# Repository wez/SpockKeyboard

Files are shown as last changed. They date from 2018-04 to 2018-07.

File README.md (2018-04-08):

# "Spock" Keyboard

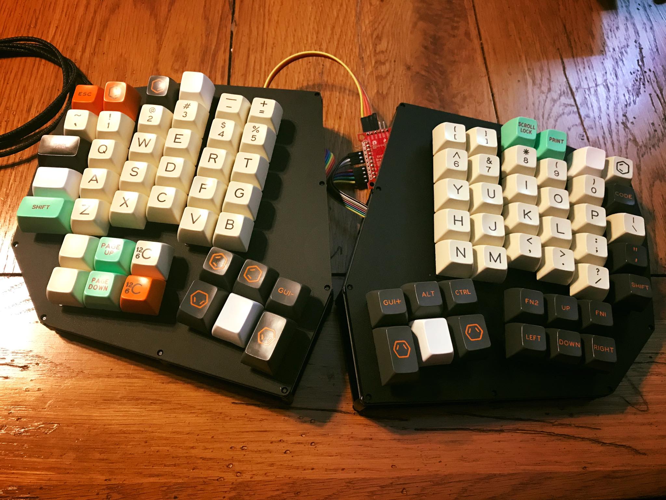
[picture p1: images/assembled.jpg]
Assembled board


This repo holds schematics and code for the Spock keyboard that was
designed by me (Wez Furlong) and modeled on my hands.

The keyboard is a split ergonomic layout in an ortholinear (straight columns,
aligned to your fingers rather than staggered) arrangement with splayed columns
that more closely match the finger separation when the hand is at rest,
thumb clusters to make use of the strong but underused thumbs and a cluster
for classic inverted-T arrow keys.

The Spock name comes from the finger splay which is reminiscent of the Vulcan
hand gesture.

The initial hardware revision is designed around a prototyping friendly
arrangement, with the PCB set up with a minimized keyboard matrix (saving the
headache of routing the matrix while soldering) that is terminated at header
blocks.  No controller hardware is proscribed, making this a more convenient
physical base for experimenting with different controller and interfaces (USB,
BLE and so on).

## What's in this repo?

The hardware directory holds the kicad pcb defintion, gerber files and plate
definitions suitable for building a sandwich style case.  The PCB and gerber
files meet the DRC requirements for [Seeed's PCB fabrication service](https://www.seeedstudio.com/fusion_pcb.html).
The case design files are suitable for use with [Ponoko's service](http://www.ponoko.com).

The Spockduino directory holds some basic code for a keyboard firmware that uses
the Adafruit Feather M0 Express controller, and a SparkFun SX1509 breakout to
implement a USB keyboard.

## Keyboard Layout Editor

You can view the layout for the left hand here:

http://www.keyboard-layout-editor.com/#/gists/912c57ebc2bcc78ba9ccc6bbb83db161

## Bill of Materials

Should you decide to build one of these for yourself, you will need:

* 84 x Cherry MX compatible PCB mount key switches (each half requires 42)
* 70 x 1u Cherry MX key caps
* 8 x 1.25u Cherry MX key caps
* 6 x 1.5u Cherry MX key caps
* 84 x 1N4148 signal diodes
* 20 x M3 spacer to hold the case top and bottom apart.  Choose the height
  that meets your taste and internal electroncs selection.
* 20 x M3 nuts
* 20 x M3 screws
* Top and bottom plate.  See [hardware/spock-case-ponoko-p2.svg](https://github.com/wez/SpockKeyboard/blob/master/hardware/spock-case-ponoko-p2.svg) for left+right and top+bottom.
  I recommend using matte acrylic for its appealing combination of weight, appearance and price.
  Note that you don't strictly need the plates if you want to rock a bare PCB, but you should
  take care to avoid shorting the contacts under the PCB.
* 2x 2x12 header block.  Pick this to match your wiring.  I used right angled
  male header block to save on vertical space.
* Microcontroller of your choice.  I'm using an [Adafruit Feather M0 Express](https://www.adafruit.com/product/3403)
  with the Spockduino code.  You should be able to use other Feather boards without
  changing the wiring.
* 1x [SX1509 IO Expander](https://www.sparkfun.com/products/13601)
* Misc jumper wires
* 2x Jack and 1x connecting cable with 4+ wires.  Some folks like [TRRS](https://www.sparkfun.com/products/11570) audio cables and
  jacks, and others like [RJ45 jacks](https://www.sparkfun.com/products/643) ([+breakout](https://www.sparkfun.com/products/716)) and cables.

note: you can trade two of the 1.25u key caps in the thumb clusters for 1u to make
room to trade two of the other 1.25u caps with 1.5u caps for a total of 72x 1u caps,
4x 1.25u caps and 8x 1.5u caps.

There are no explicitly designed in attachment points for the controller, expander
or jacks so you may want to apply friction, tape or hot glue as suits your taste
and overall assembly.

## Wiring/Assembly

The PCB is reversible and can be used for a left or right hand.  For left hand
assembly you will place the switches and diodes on the side that has the
keyswitch labels (eg: `k01` through `k77`).  For the right hand you will place
them on the other side of the board.

If you are using the top plate, take care to assemble in the order described
below as it can be difficult to go back to correct a missed step once you
start soldering the keyswitches.

This initial rev is designed for prototyping, so I attached header to the Feather
and expander breakout boards and used jumper cables to connect them up.  Play
around with this before you start soldering keyswitches to make sure that you
can fit everything together.

1. Solder the diodes first.  The black bar of the diode must be aligned to the thicker
   white bar.  For the left hand the diodes go in on the side with the `dkXX` labels,
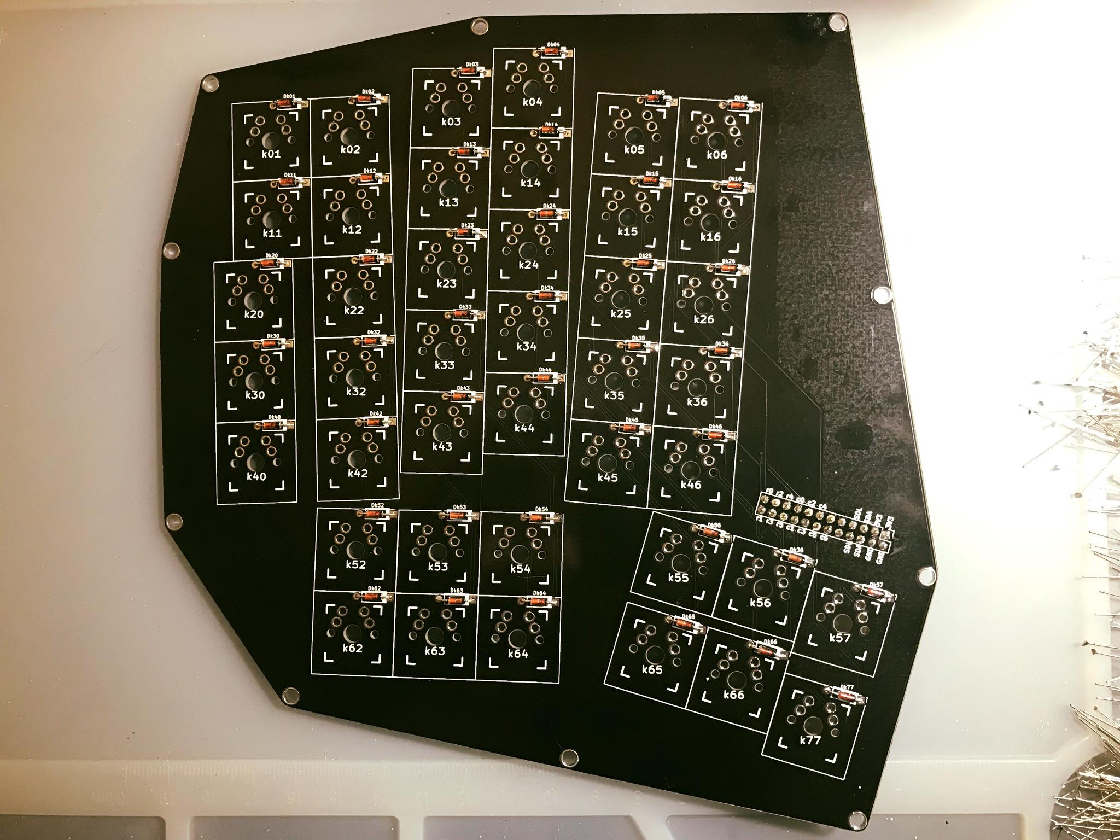
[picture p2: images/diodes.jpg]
diodes
   for the right hand they go on the opposite side. 
2. Solder the header block second.  If you are using a plate the header pins must be
   on the other side of the board from the diodes.  If you are rocking a plateless
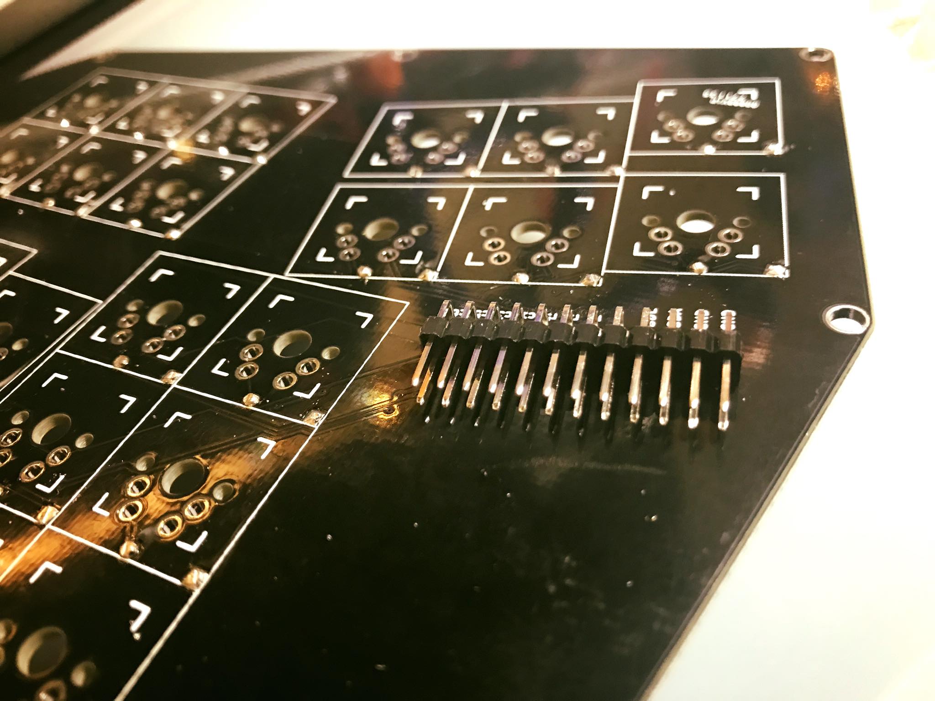
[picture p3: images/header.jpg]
header
   build then you may want the header pins on the top side. 
3. If using a plate, insert the M3 nuts and spacers now.  The nuts go on the same side
   as the diodes, with the spacers on the other side.
4. Place the plate; it goes on the same side as the diodes and should click in
   and lightly grip on the top of the M3 spacers where they protude through
   the M3 nuts
5. Place the key switches through the plate.  The switch stem should be on the same
   side of the board as the diodes and plate.  The switch should friction fit
   in the PCB.  Take care to check that both of the pins on the underside of
   the switch are protuding from the holds on the reverse of the PCB.  You should
   see the pins in the holes and they may protude by about 1mm.  It is possible to
   fold a pin over when placing it, so you may need to wiggle it out of the plate and pcb and
   straighten up the pin.   Make sure that you check every switch!
6. Satisfy yourself that you can assemble the case and house the controller and expander
   before you go further.
7. Solder in the key switches.  Make sure that you solder both pins on each switch!

The Spockduino code assumes that you connected the pins like this:

### Feather

The Feather is attached to the left hand.  Take care: the header block
labels on the backside are wrong; see the errata below!

* Pins labelled `A0`-`A5` on the left side are connected to `r0`-`r5` in the header block
* Pins labelled `5`-`12` on the right side are connected to `c0`-`c6` in the header block
* `3V3`, `GND`, `SDA`, `SDL` are connected to the pins with the same names
  on the IO expander.  These 4 lines are intended to be carried over
  the connecting cable between the halves so you may want to connect the
  feather to a TRRS or RJ45 block and do the same on the other half
  for the Expander

### SX 1509

The SX1509 is attached to the right hand. Take care: the header block
labels on the backside are wrong; see the errata below!

* Pins `0`-`5` are connected to `r0`-`r5` in the header block.
* Pins `8`-`14` are connected to `c0`-`c6` in the header block.
* `3V3`, `GND`, `SDA`, `SDL` are connected to the pins with the same names
  on the Feather as noted above.

### Flashing

Use the arduino IDE to upload the spock sketch to the device.  I found
that this often requires a couple of attempts with the Feather M0 Express,
as the bootloader seems to take a little longer to kick in than the uploader
expects.

## Errata

The first and current rev of the PCB design has incorrect labels for the header
block on the back side of the PCB.  The labels on the front side are correct.
In case you are unsure which is the front, the front side of the pcb also has
labels for the switch positions.

## License and Copying

Unless stated in individual files, the contents of this repo are made available
under the terms of the MIT License.

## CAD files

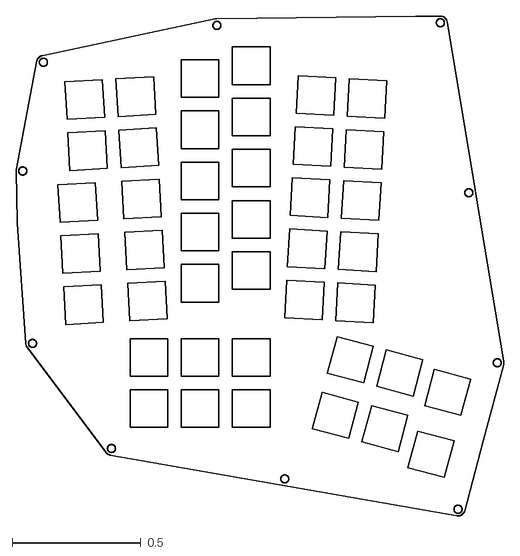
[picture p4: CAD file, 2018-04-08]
hardware/switch-plate-full.dxf
1.89 x 1.94

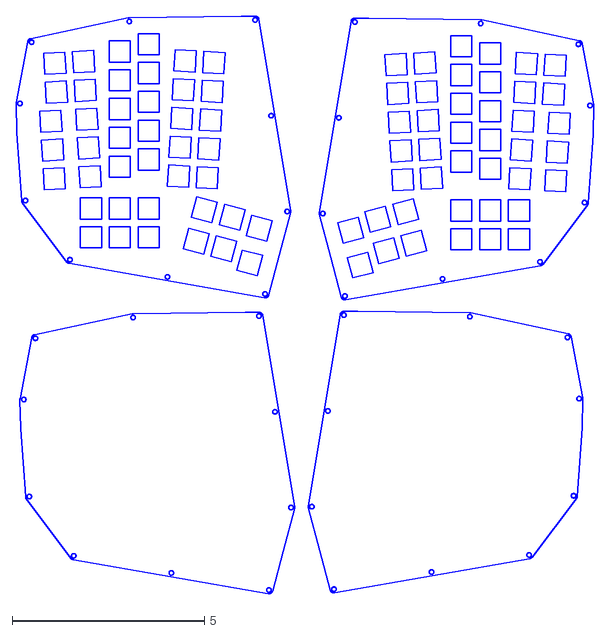
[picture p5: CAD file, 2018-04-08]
hardware/spock-case-ponoko-p2.dxf
15.0 x 15.0

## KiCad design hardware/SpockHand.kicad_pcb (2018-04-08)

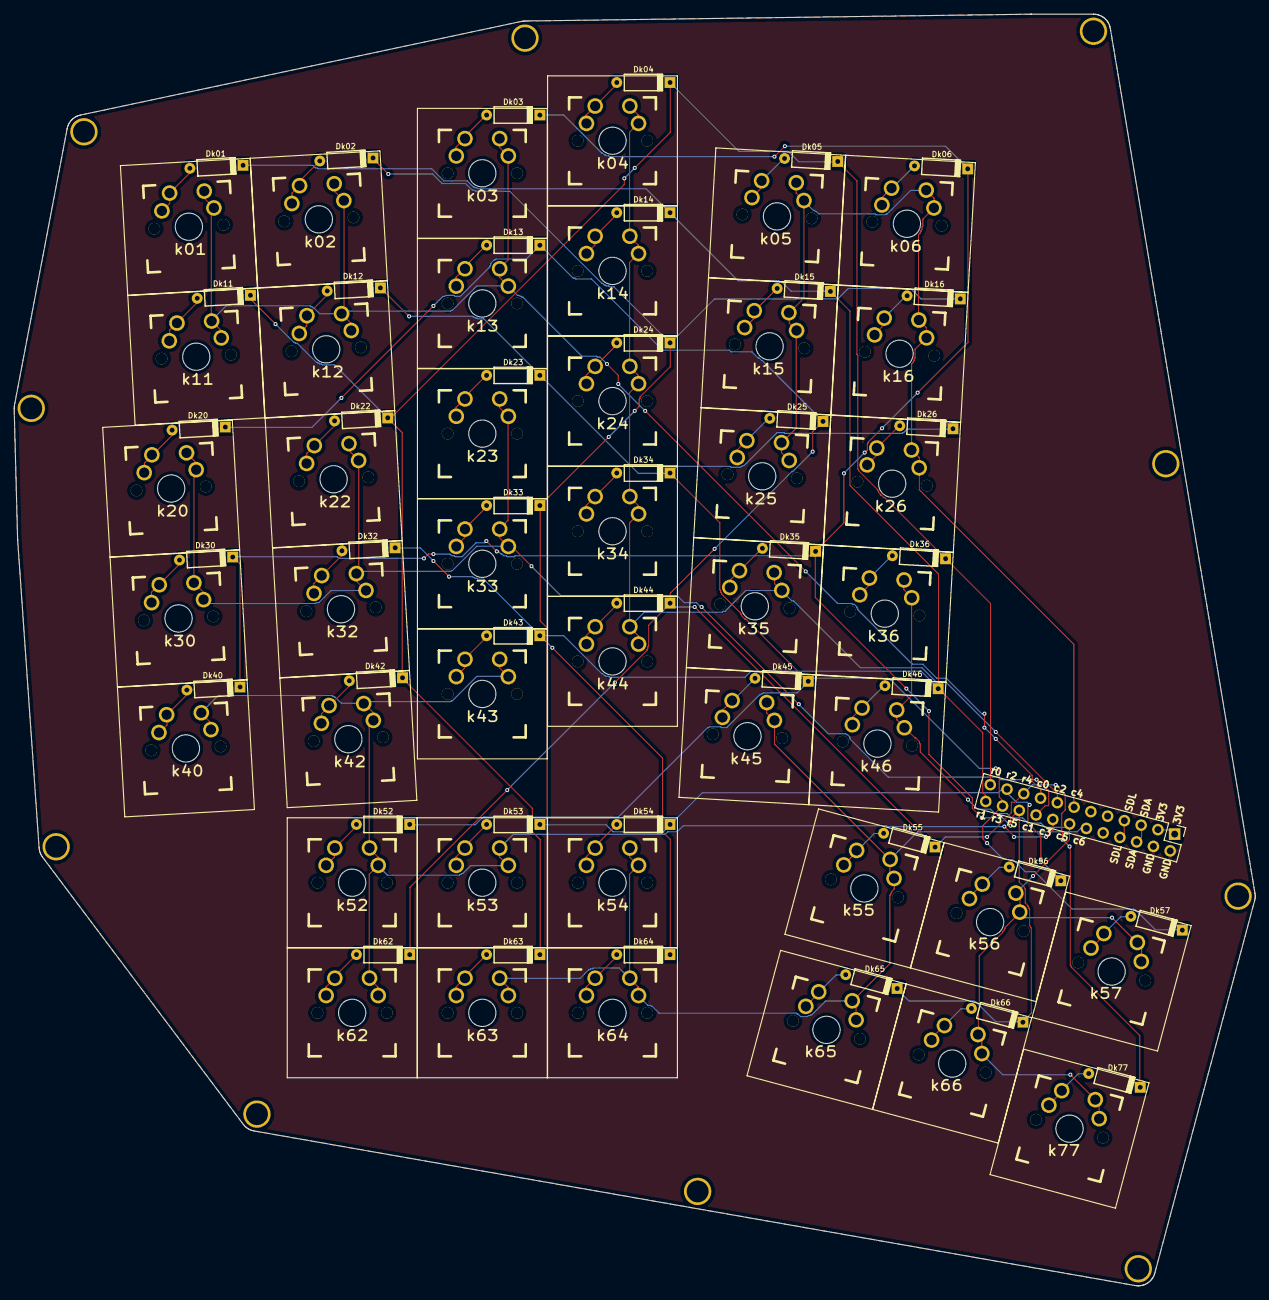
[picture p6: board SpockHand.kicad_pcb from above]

Board: 2 copper layers, 181.6 x 186.1 mm, 94 parts (0 on the bottom side), 55 nets.

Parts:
CP0: VAL**; CP0
CP1: VAL**; CP1
CP2: VAL**; CP2
CP3: VAL**; CP3
CP4: VAL**; CP4
CP5: VAL**; CP5
CP6: VAL**; CP6
CP7: VAL**; CP7
CP8: VAL**; CP8
CP9: VAL**; CP9
Dk01: D; Dk01
Dk02: D; Dk02
Dk03: D; Dk03
Dk04: D; Dk04
Dk05: D; Dk05
Dk06: D; Dk06
Dk11: D; Dk11
Dk12: D; Dk12
Dk13: D; Dk13
Dk14: D; Dk14
Dk15: D; Dk15
Dk16: D; Dk16
Dk20: D; Dk20
Dk22: D; Dk22
Dk23: D; Dk23
Dk24: D; Dk24
Dk25: D; Dk25
Dk26: D; Dk26
Dk30: D; Dk30
Dk32: D; Dk32
Dk33: D; Dk33
Dk34: D; Dk34
Dk35: D; Dk35
Dk36: D; Dk36
Dk40: D; Dk40
Dk42: D; Dk42
Dk43: D; Dk43
Dk44: D; Dk44
Dk45: D; Dk45
Dk46: D; Dk46
Dk52: D; Dk52
Dk53: D; Dk53
Dk54: D; Dk54
Dk55: D; Dk55
Dk56: D; Dk56
Dk57: D; Dk57
Dk62: D; Dk62
Dk63: D; Dk63
Dk64: D; Dk64
Dk65: D; Dk65
Dk66: D; Dk66
Dk77: D; Dk77
k01: >VALUE; k01
k02: >VALUE; k02
k03: >VALUE; k03
k04: >VALUE; k04
k05: >VALUE; k05
k06: >VALUE; k06
k11: >VALUE; k11
k12: >VALUE; k12
k13: >VALUE; k13
k14: >VALUE; k14
k15: >VALUE; k15
k16: >VALUE; k16
k20: >VALUE; k20
k22: >VALUE; k22
k23: >VALUE; k23
k24: >VALUE; k24
k25: >VALUE; k25
k26: >VALUE; k26
k30: >VALUE; k30
k32: >VALUE; k32
k33: >VALUE; k33
k34: >VALUE; k34
k35: >VALUE; k35
k36: >VALUE; k36
k40: >VALUE; k40
k42: >VALUE; k42
k43: >VALUE; k43
k44: >VALUE; k44
k45: >VALUE; k45
k46: >VALUE; k46
k52: >VALUE; k52
k53: >VALUE; k53
k54: >VALUE; k54
k55: >VALUE; k55
k56: >VALUE; k56
k57: >VALUE; k57
k62: >VALUE; k62
k63: >VALUE; k63
k64: >VALUE; k64
k65: >VALUE; k65
k66: >VALUE; k66
k77: >VALUE; k77

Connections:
unnamed: Dk11.2, k11.2, k11.2a
unnamed: Dk22.2, k22.2, k22.2a
unnamed: Dk04.2, k04.2, k04.2a
unnamed: Dk42.2, k42.2, k42.2a
unnamed: Dk05.2, k05.2, k05.2a
unnamed: Dk36.2, k36.2, k36.2a
unnamed: Dk63.2, k63.2, k63.2a
unnamed: Dk01.2, k01.2, k01.2a
unnamed: Dk32.2, k32.2, k32.2a
unnamed: Dk14.2, k14.2, k14.2a
unnamed: Dk43.2, k43.2, k43.2a
unnamed: Dk15.2, k15.2, k15.2a
unnamed: Dk46.2, k46.2, k46.2a
unnamed: Dk64.2, k64.2, k64.2a
unnamed: Dk02.2, k02.2, k02.2a
unnamed: Dk33.2, k33.2, k33.2a
unnamed: Dk24.2, k24.2, k24.2a
unnamed: Dk53.2, k53.2, k53.2a
unnamed: Dk16.2, k16.2, k16.2a
unnamed: Dk56.2, k56.2, k56.2a
unnamed: Dk54.2, k54.2, k54.2a
unnamed: Dk12.2, k12.2, k12.2a
unnamed: Dk23.2, k23.2, k23.2a
unnamed: Dk34.2, k34.2, k34.2a
unnamed: Dk52.2, k52.2, k52.2a
unnamed: Dk26.2, k26.2, k26.2a
unnamed: Dk57.2, k57.2, k57.2a
unnamed: Dk45.2, k45.2, k45.2a
unnamed: Dk13.2, k13.2, k13.2a
unnamed: Dk20.2, k20.2, k20.2a
unnamed: Dk44.2, k44.2, k44.2a
unnamed: Dk62.2, k62.2, k62.2a
unnamed: Dk25.2, k25.2, k25.2a
unnamed: Dk77.2, k77.2, k77.2a
unnamed: Dk55.2, k55.2, k55.2a
unnamed: Dk03.2, k03.2, k03.2a
unnamed: Dk30.2, k30.2, k30.2a
unnamed: Dk35.2, k35.2, k35.2a
unnamed: Dk40.2, k40.2, k40.2a
unnamed: Dk06.2, k06.2, k06.2a
unnamed: Dk66.2, k66.2, k66.2a
unnamed: Dk65.2, k65.2, k65.2a
col0: k01.1, k01.1a, k02.1, k02.1a, k03.1, k03.1a, k11.1, k11.1a, k12.1, k12.1a, k13.1, k13.1a
col1: k20.1, k20.1a, k22.1, k22.1a, k23.1, k23.1a, k30.1, k30.1a, k32.1, k32.1a, k33.1, k33.1a
col2: k04.1, k04.1a, k14.1, k14.1a, k24.1, k24.1a, k34.1, k34.1a, k35.1, k35.1a, k44.1, k44.1a
col3: k40.1, k40.1a, k42.1, k42.1a, k43.1, k43.1a, k52.1, k52.1a, k53.1, k53.1a, k62.1, k62.1a
col4: k05.1, k05.1a, k06.1, k06.1a, k15.1, k15.1a, k16.1, k16.1a, k25.1, k25.1a, k26.1, k26.1a
col5: k36.1, k36.1a, k46.1, k46.1a, k56.1, k56.1a, k57.1, k57.1a, k66.1, k66.1a, k77.1, k77.1a
col6: k45.1, k45.1a, k54.1, k54.1a, k55.1, k55.1a, k63.1, k63.1a, k64.1, k64.1a, k65.1, k65.1a
row0: Dk04.1, Dk05.1, Dk11.1, Dk22.1, Dk36.1, Dk42.1, Dk63.1
row1: Dk01.1, Dk14.1, Dk15.1, Dk32.1, Dk43.1, Dk46.1, Dk64.1
row2: Dk02.1, Dk16.1, Dk24.1, Dk33.1, Dk53.1, Dk54.1, Dk56.1
row3: Dk12.1, Dk23.1, Dk26.1, Dk34.1, Dk45.1, Dk52.1, Dk57.1
row4: Dk13.1, Dk20.1, Dk25.1, Dk44.1, Dk55.1, Dk62.1, Dk77.1
row5: Dk03.1, Dk06.1, Dk30.1, Dk35.1, Dk40.1, Dk65.1, Dk66.1

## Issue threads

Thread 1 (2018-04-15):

Will it support QMK eventually ?

harshitgoel96, 2018-04-15:
Hi @wez

I love the design of the keyboard. It looks like it is currently running a very basic firmware. I just want to know if it would ever run QMK ?

wez, 2018-04-15:
It shouldn't be especially difficult to get QMK running for this board.  I didn't start with QMK because QMK is still reasonably AVR centric and the controller I'm using didn't have great support last time I checked.  The hardest part is the matrix/keymap stuff, but that is already basically there as the KEYMAP macro I've used here is deliberately similar to the QMK style.

However, I don't have immediate plans to port QMK to this board myself.

harshitgoel96, 2018-04-19:
Feather 32u4 is supported by QMK out of the box. So I am assuming you are using M0 variant of feather. well its a nice layout, I might build one eventually as the ergodox I have is not for my hand. I have long fingers but short thumb. so this results in very bad thumb cluster reach.

wez, 2018-09-12:
I just pushed support for QMK to my own qmk fork; see the commit referenced above!

Closed 2018-09-12.

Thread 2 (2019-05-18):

nRF52 Split Bluetooth Keyboard

shaoyuan1943, 2019-05-18:
Hi, wez
I don't know your email so I'm sorry to bother you on github. I saw your Split Bluetooth Keyboard build log in here: https://gist.github.com/wez/b30683a4dfa329b86b9e0a2811a8c593

I have two nRF52832 board, so I want to build split bluetooth keyboard like you, but now I get a problem. One nRF52832 is central(right hand), one is peripheral(left hand), right hand connect left hand by UART and read left hand key matrix, at last, right hand send key matrix by bluetooth-hid to PC.

**The problem is: when two nRF52832 board connected and right hand read key matrix succeed, but right hand HID send key matrix failed, I don't know why, I can't found any documents for that.**

// reported is false
bool reported = hid.keyboardReport(mods, report);

Can you help let me know why? Thank you very much for your gist.

Best regards.
lennon.c

Closed 2019-05-20.

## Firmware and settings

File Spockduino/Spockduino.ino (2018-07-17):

#define WAT 0
#include "HID.h"
#include "HIDTables.h"
#include "Keyboard.h"

#define HID_KEYBOARD_A HID_KEYBOARD_A_AND_A
#define HID_KEYBOARD_B HID_KEYBOARD_B_AND_B
#define HID_KEYBOARD_C HID_KEYBOARD_C_AND_C
#define HID_KEYBOARD_D HID_KEYBOARD_D_AND_D
#define HID_KEYBOARD_E HID_KEYBOARD_E_AND_E
#define HID_KEYBOARD_F HID_KEYBOARD_F_AND_F
#define HID_KEYBOARD_G HID_KEYBOARD_G_AND_G
#define HID_KEYBOARD_H HID_KEYBOARD_H_AND_H
#define HID_KEYBOARD_I HID_KEYBOARD_I_AND_I
#define HID_KEYBOARD_J HID_KEYBOARD_J_AND_J
#define HID_KEYBOARD_K HID_KEYBOARD_K_AND_K
#define HID_KEYBOARD_L HID_KEYBOARD_L_AND_L
#define HID_KEYBOARD_M HID_KEYBOARD_M_AND_M
#define HID_KEYBOARD_N HID_KEYBOARD_N_AND_N
#define HID_KEYBOARD_O HID_KEYBOARD_O_AND_O
#define HID_KEYBOARD_P HID_KEYBOARD_P_AND_P
#define HID_KEYBOARD_Q HID_KEYBOARD_Q_AND_Q
#define HID_KEYBOARD_R HID_KEYBOARD_R_AND_R
#define HID_KEYBOARD_S HID_KEYBOARD_S_AND_S
#define HID_KEYBOARD_T HID_KEYBOARD_T_AND_T
#define HID_KEYBOARD_U HID_KEYBOARD_U_AND_U
#define HID_KEYBOARD_V HID_KEYBOARD_V_AND_V
#define HID_KEYBOARD_W HID_KEYBOARD_W_AND_W
#define HID_KEYBOARD_X HID_KEYBOARD_X_AND_X
#define HID_KEYBOARD_Y HID_KEYBOARD_Y_AND_Y
#define HID_KEYBOARD_Z HID_KEYBOARD_Z_AND_Z

#define HID_KEYBOARD_BRACKET_RIGHT HID_KEYBOARD_RIGHT_BRACKET_AND_RIGHT_CURLY_BRACE
#define HID_KEYBOARD_BRACKET_LEFT HID_KEYBOARD_LEFT_BRACKET_AND_LEFT_CURLY_BRACE
#define HID_KEYBOARD_APOSTROPHE HID_KEYBOARD_QUOTE_AND_DOUBLEQUOTE
#define HID_KEYBOARD_GRAVE HID_KEYBOARD_GRAVE_ACCENT_AND_TILDE

#define HID_KEYBOARD_1 HID_KEYBOARD_1_AND_EXCLAMATION_POINT
#define HID_KEYBOARD_2 HID_KEYBOARD_2_AND_AT
#define HID_KEYBOARD_3 HID_KEYBOARD_3_AND_POUND
#define HID_KEYBOARD_4 HID_KEYBOARD_4_AND_DOLLAR
#define HID_KEYBOARD_5 HID_KEYBOARD_5_AND_PERCENT
#define HID_KEYBOARD_6 HID_KEYBOARD_6_AND_CARAT
#define HID_KEYBOARD_7 HID_KEYBOARD_7_AND_AMPERSAND	
#define HID_KEYBOARD_8 HID_KEYBOARD_8_AND_ASTERISK	
#define HID_KEYBOARD_9 HID_KEYBOARD_9_AND_LEFT_PAREN	
#define HID_KEYBOARD_0 HID_KEYBOARD_0_AND_RIGHT_PAREN

#define KEYBOARD_MODIFIER_LEFTCTRL 1<<0
#define KEYBOARD_MODIFIER_LEFTSHIFT 1<<1
#define KEYBOARD_MODIFIER_LEFTALT 1<<2
#define KEYBOARD_MODIFIER_LEFTGUI 1<<3
#define KEYBOARD_MODIFIER_RIGHTCTRL 1<<4
#define KEYBOARD_MODIFIER_RIGHTSHIFT 1<<5
#define KEYBOARD_MODIFIER_RIGHTALT 1<<6
#define KEYBOARD_MODIFIER_RIGHTGUI 1<<7


#include "keymap.h"
#include "keyscanner.h"


void setup() 
{
#if WAT
  Serial.begin(115200);
#endif
  Keyboard.begin();

  initKeyScanner();
  resetKeyMatrix();
}

void loop() 
{
  applyMatrix();
}

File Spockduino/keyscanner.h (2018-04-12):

#pragma once
#include "sx1509.h"

// This file holds the code that scans the keyboard matrix.
// It uses an SX1509 IO expander to read the matrix for the
// right hand side and an Adafruit Feather M0 for the left
// hand side.  The readMatrix() function is the main function
// of interest.

// NOTE: if you change the row or column mappings here, you
// will probably also need to change the KEYMAP macro defined
// in keymap.h.
// These are the pin assignments to the Feather M0 Express.
// The array lists the c0-c6 column assignments to the
// header block.
static const int colPins[] = {5,6,9,10,11,12,13};
// These are r0-r5 assignments
static const int rowPins[] = {14,15,16,17,18,19};

// These are pin assignments to the sx1509 IO multiplexer.
// The column pins are attached to c0-c6, and the row
// pins to r0-r5
static const int expColPins[] = {8,9,10,11,12,13,14};
static const int expRowPins[] = {0,1,2,3,4,5};

static struct matrix_t debounceMatrix;
static struct matrix_t localMatrix;
static constexpr int kDebounceIterations = 1;
static int debouncing = kDebounceIterations;
static SX1509 expander;

void initKeyScanner() {
  expander.init();
  memset(&debounceMatrix, 0, sizeof(debounceMatrix));
  memset(&localMatrix, 0, sizeof(localMatrix));
  debouncing = kDebounceIterations;

  // Set all the rows to output-high
  for (const auto &pin : rowPins) {
    pinMode(pin, OUTPUT);
    digitalWrite(pin, HIGH);
  }

  // 0 is output
  expander.directionA(0b11000000);
  // 1 is high
  expander.dataA(0b00111111);

  // Set all the columns to input-pullup
  for (const auto &pin : colPins) {
    pinMode(pin, INPUT_PULLUP);
  }

  // 1 is input
  expander.directionB(0b01111111);
  // 1 is pull up enabled
  expander.pullupB(0b01111111);
}

void scanMatrix() {
  for (int rowNum = 0; rowNum < sizeof(rowPins) / sizeof(rowPins[0]);
       ++rowNum) {
    // Set just this row to LOW in the expander; the rest are set HIGH
    expander.dataA(~(1<<rowNum));
    digitalWrite(rowPins[rowNum], LOW);
    delayMicroseconds(25);

    uint16_t rowBits = 0;
    uint8_t expanderBits;

    // Read all the columns from the expander in a single IO op
    if (!expander.readDataB(expanderBits)) {
      // Pretend that they are all high if there is a comms error
      expanderBits = 0xff;
    }

    for (int colNum = 0; colNum < sizeof(colPins) / sizeof(colPins[0]);
         ++colNum) {
      if (!digitalRead(colPins[colNum])) {
        rowBits |= 1 << (colNum);
      }
      if ((expanderBits & (1<<colNum)) == 0) {
        rowBits |= 1 << (colNum + 7);
      }
    }

    if (rowBits != debounceMatrix.rows[rowNum]) {
      // Switch status changed, reset the debounce counter
      debouncing = kDebounceIterations;
      debounceMatrix.rows[rowNum] = rowBits;
    }

    digitalWrite(rowPins[rowNum], HIGH);
  }

  if (debouncing) {
    if (--debouncing) {
      delay(1);
    } else {
      // We got a stable result, transfer the data to the matrix
      localMatrix = debounceMatrix;
    }
  }
}

struct matrix_t readMatrix() {
  scanMatrix();
  return localMatrix;
}

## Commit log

2018-04-08 Add spock keyboard bits
    [SpockHand-B.Cu.gbl, SpockHand-B.Mask.gbs, SpockHand-B.SilkS.gbo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]
2018-04-12 fix dual role ctrl/esc tap and hold behavior
    [Spockduino.ino, keyscanner.h]
2018-04-12 Use a more targeted sx1509 driver
    The example sparkfun driver does a ton of IO for every operation,
    which eats into our headroom for responding to keypresses.
